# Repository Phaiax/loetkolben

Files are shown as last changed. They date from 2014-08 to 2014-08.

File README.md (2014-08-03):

##### Why?

The soldering iron station I used was much older than me and had a few drawbacks, including a random heat-to-infinity function if you don't pay attention. So I decided to renew it, but using the old housing and transformers.

##### PCB:

For more Information refer to the pcb, its full of comments.

+ pcb/alte_schaltung_*.*     - the legacy reverse engeneered pcb. (Including switch, trimmer and plugs which are not directly on the pcb)
+ pcb/neue_schaltung.*	     - my new pcb, double sided, excluding switches, the trimmer, the plugs.
+ pcb/out/		     - this is outdated and need to be regenerated! (the 7905 has different pinouts)

##### Features:

+ galvanic seperated
+ Auto timeout (currently 2 min)
+ Enough power (<30s to 300°C)
+ Temperature Display
+ Switch heat on @ zero passing of sine wave.
+ On and off via software (turn trim resistor to left/right dead stop)
+ Display in house temperature

##### Missing: 

+ a nice controller (kalman or at least something which can filter the white noise of the measurements). I really would like to improve this, but currently I'm using 2032 od 2048 bytes of flash. An AtTiny861A would have been better :(

##### Build:

+ If you should ever build this, make shure you understand every part of the hardware and the software. You need to calibrate the timer value and the temperature calculation coefficient and offset.
+ Depending on the used voltages and transformers, you may need to adjust some resistors etc.
+ Pay attention when handeling voltages above 30V, and even more attention with 110 or 230V. Always remove plug before opening the housing and vice versa.
+ I needed to force the position of the holes and the led to match the legacy pcb. You may want to move the holes.
+ Check which type of thermocouple (=thermoeelement) you are using and adjust the amplification if neccessary.

##### Possible improvements:

+ Use Attiny861A with 8000 instead of 2000 kb flash and add more features to the software.
+ Make the led to light up at both the positive and negative half wave.
+ Make some EMV improvements.
+ You probably can omit the negative voltage generation, the currently used opamp is capable of only using a positive one. (I former planed to use another opamp).
+ The polygons that create the ground area can be adjusted, so the triac and the led have more spacing to the surrounding ground area.

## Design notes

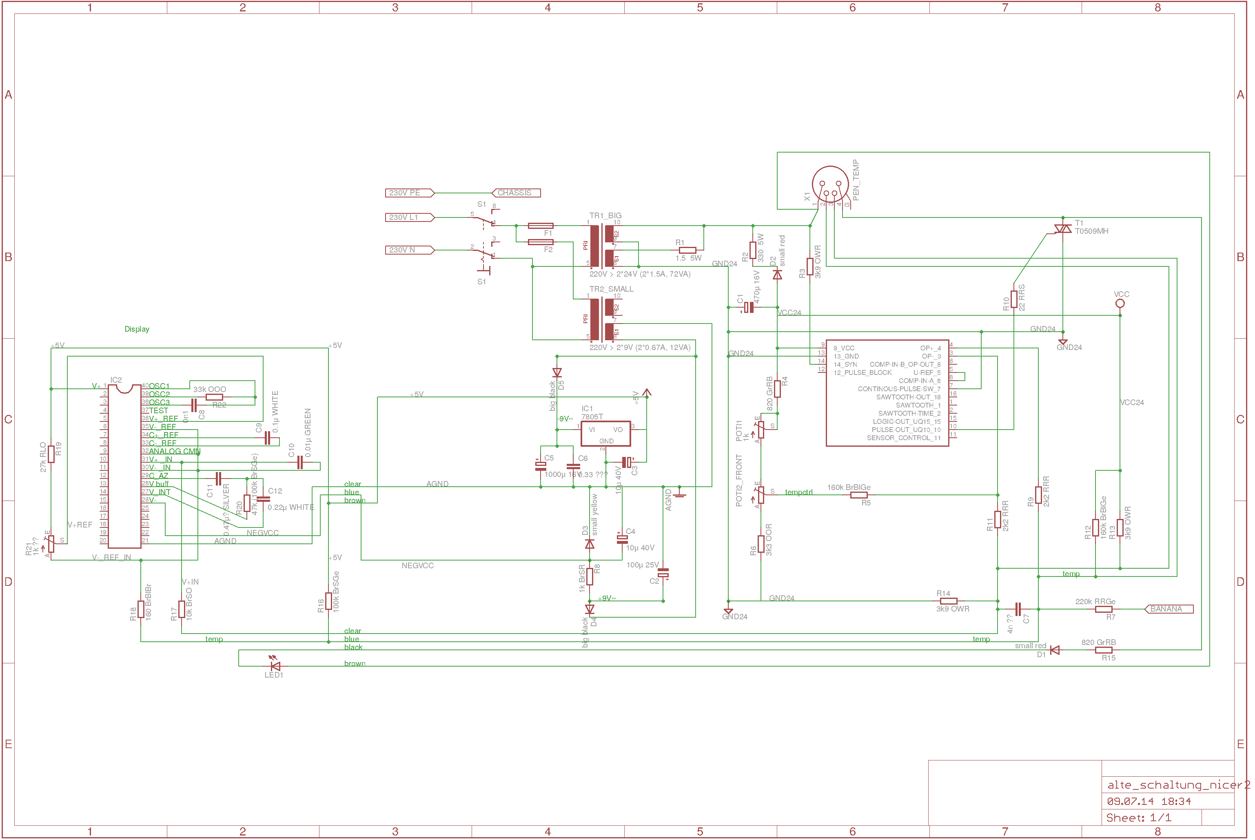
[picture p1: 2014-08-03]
pcb/schaltplan.png

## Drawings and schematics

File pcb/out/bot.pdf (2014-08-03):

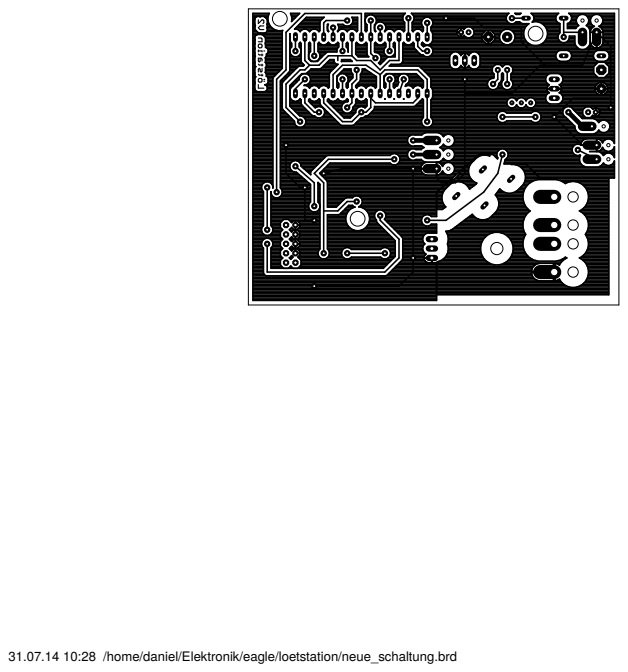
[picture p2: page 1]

31.07.14 10:28 /home/daniel/Elektronik/eagle/loetstation/neue_schaltung.brd

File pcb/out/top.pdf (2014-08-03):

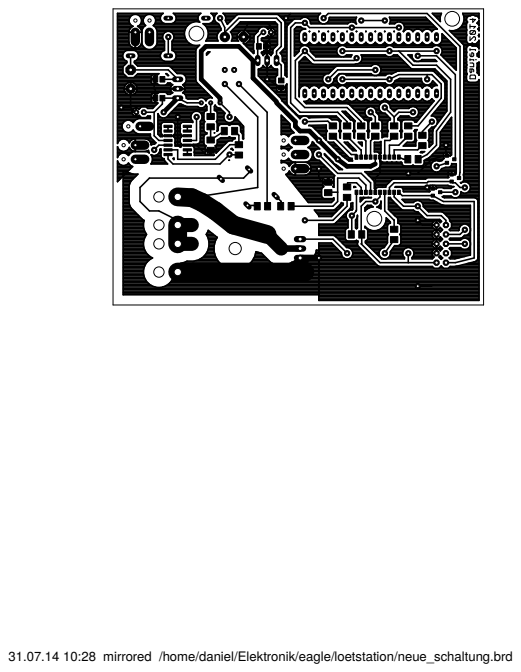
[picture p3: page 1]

31.07.14 10:28 mirrored /home/daniel/Elektronik/eagle/loetstation/neue_schaltung.brd

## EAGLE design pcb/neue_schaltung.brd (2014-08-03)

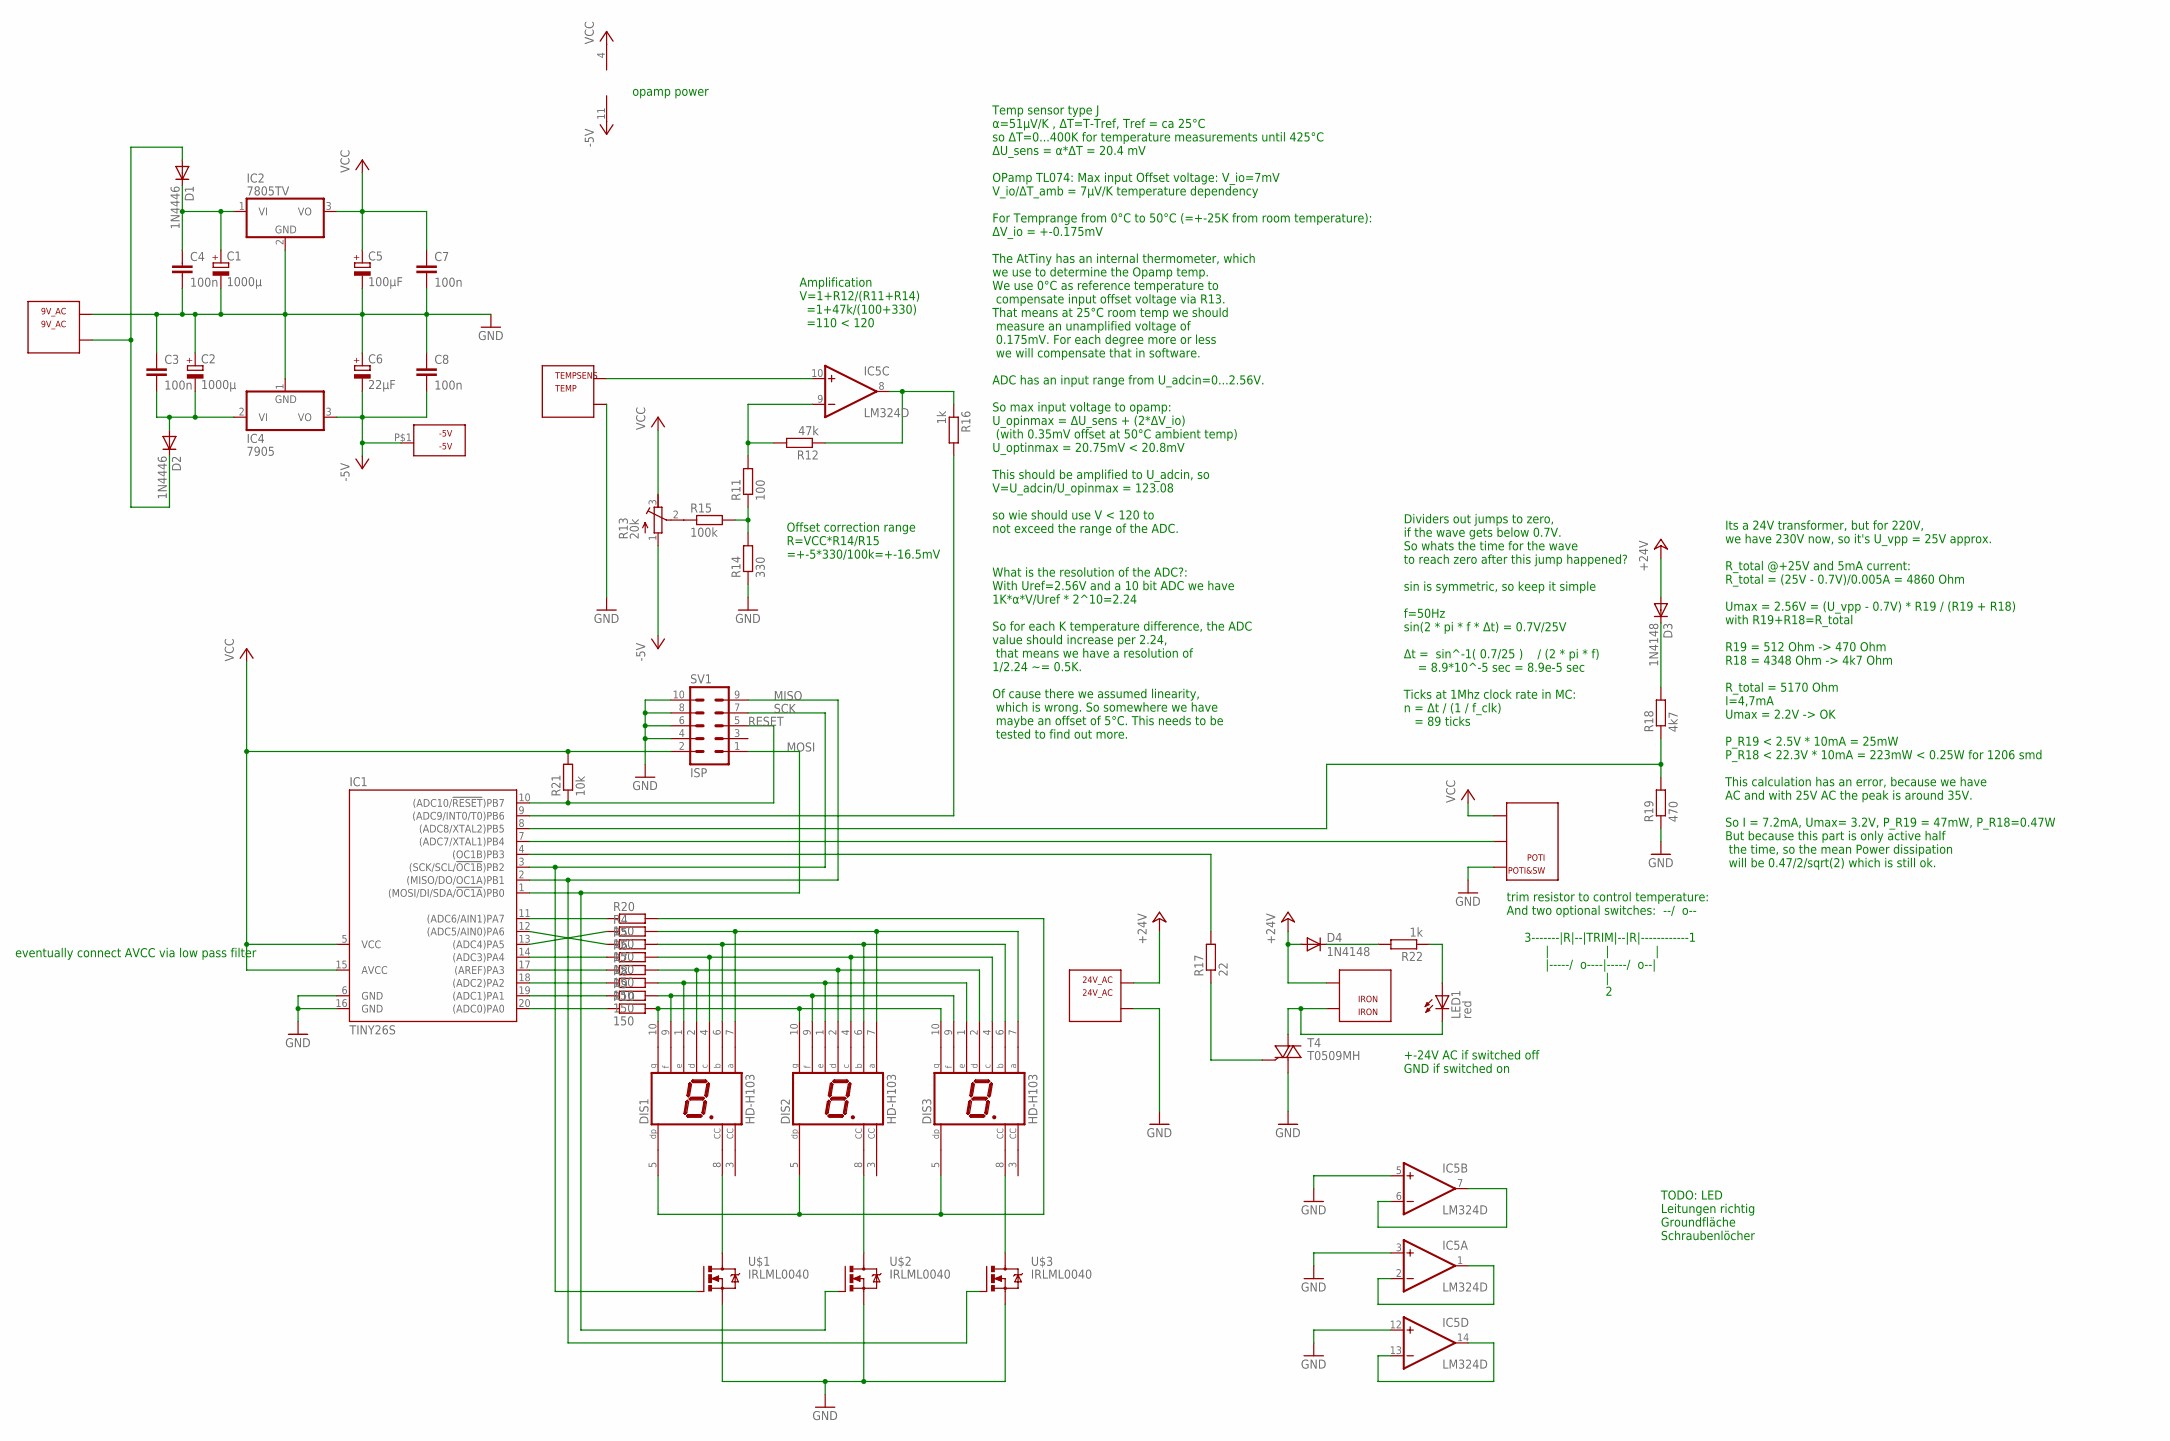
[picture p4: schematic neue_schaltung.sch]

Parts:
9V_AC: 9V_AC; WIREPADX2_2H
24V_AC: 24V_AC; WIREPADX2_2H_BIG
-5V: -5V; WIREPAD_2H
C1, C2: 1000µ; E5-10,5
C3, C4, C7, C8: 100n; C0805
C5: 100µF; E2-5
C6: 22µF; E2-5
D1, D2: 1N4446; DO35-10
D3, D4: 1N4148; DO35-10
DIS1, DIS2, DIS3: HD-H103; HDSP-M
IC1: TINY26S; SO20L
IC2: 7805TV; TO220V
IC4: 7905; TO220H
IC5: LM324D; SO14
IRON: IRON; WIREPADX2_2H_BIG
LED1: red; LED5MM
POTI&SW: POTI; WIREPADX3_2H
R4, R5, R6, R7, R8, R9, R10, R20: 150; M1206
R11: 100; M1206
R12: 47k; M1206
R13: 20k; RTRIM64W
R14: 330; M1206
R15: 100k; M1206
R16, R22: 1k; M1206
R17: 22; M1206
R18: 4k7; M1206
R19: 470; M1206
R21: 10k; M1206
SV1: ISP; ML10
T4: T0509MH; TO220AB
TEMPSENS: TEMP; WIREPADX2_2H
U$1, U$2, U$3: IRLML0040; MICRO3

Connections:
+24V: 24V_AC.P$1, D3.A, D4.A, IRON.P$2
-5V: -5V.P$1, C6.-, C8.2, IC4.3 (VO), IC5.11 (V-), R13.1 (E)
GND: 9V_AC.P$1, 24V_AC.P$2, C1.-, C2.+, C3.1, C4.2, C5.-, C6.+, C7.2, C8.1, IC1.6 (GND), IC1.16 (GND), IC2.2 (GND), IC4.1 (GND), IC5.3 (+IN), IC5.5 (+IN), IC5.12 (+IN), POTI&SW.P$1, R14.1, R19.1, SV1.4, SV1.6, SV1.8, SV1.10, T4.1 (A1), TEMPSENS.P$2, U$1.2 (S), U$2.2 (S), U$3.2 (S)
MISO: IC1.2 ((MISO/DO/OC1A)PB1), SV1.9, U$3.1 (G)
MOSI: IC1.1 ((MOSI/DI/SDA/!OC1A!)PB0), SV1.1, U$2.1 (G)
unnamed: DIS1.10 (G), DIS2.10 (G), DIS3.10 (G), R10.2
unnamed: DIS1.9 (F), DIS2.9 (F), DIS3.9 (F), R9.2
unnamed: DIS1.1 (E), DIS2.1 (E), DIS3.1 (E), R8.2
unnamed: DIS1.2 (D), DIS2.2 (D), DIS3.2 (D), R7.2
unnamed: DIS1.4 (C), DIS2.4 (C), DIS3.4 (C), R6.2
unnamed: DIS1.6 (B), DIS2.6 (B), DIS3.6 (B), R5.2
unnamed: DIS1.7 (A), DIS2.7 (A), DIS3.7 (A), R4.2
unnamed: DIS1.5 (DP), DIS2.5 (DP), DIS3.5 (DP), R20.2
unnamed: IC1.12 ((ADC5/AIN0)PA6), R5.1
unnamed: IC1.13 ((ADC4)PA5), R4.1
unnamed: IC1.14 ((ADC3)PA4), R6.1
unnamed: IC1.17 ((AREF)PA3), R7.1
unnamed: IC1.18 ((ADC2)PA2), R8.1
unnamed: IC1.19 ((ADC1)PA1), R9.1
unnamed: IC1.20 ((ADC0)PA0), R10.1
unnamed: DIS1.8 (CC), U$1.3 (D)
unnamed: DIS2.8 (CC), U$2.3 (D)
unnamed: DIS3.8 (CC), U$3.3 (D)
unnamed: IC5.10 (+IN), TEMPSENS.P$1
unnamed: R13.2 (S), R15.1
unnamed: 9V_AC.P$2, D1.A, D2.C
unnamed: C2.-, C3.2, D2.A, IC4.2 (VI)
unnamed: C1.+, C4.1, D1.C, IC2.1 (VI)
unnamed: IC5.9 (-IN), R11.2, R12.2
unnamed: IC1.9 ((ADC9/INT0/T0)PB6), R16.2
unnamed: R11.1, R14.2, R15.2
unnamed: IC5.8 (OUT), R12.1, R16.1
unnamed: IRON.P$1, LED1.K (C), T4.2 (A2)
unnamed: R17.1, T4.3 (G)
unnamed: IC1.4 ((OC1B)PB3), R17.2
unnamed: IC1.7 ((ADC7/XTAL1)PB4), POTI&SW.P$2
unnamed: IC1.8 ((ADC8/XTAL2)PB5), R18.1, R19.2
unnamed: D3.C, R18.2
unnamed: IC1.11 ((ADC6/AIN1)PA7), R20.1
unnamed: D4.C, R22.2
unnamed: IC5.6 (-IN), IC5.7 (OUT)
unnamed: IC5.1 (OUT), IC5.2 (-IN)
unnamed: IC5.13 (-IN), IC5.14 (OUT)
unnamed: LED1.A, R22.1
RESET: IC1.10 ((ADC10/!RESET!)PB7), R21.1, SV1.5
SCK: IC1.3 ((SCK/SCL/!OC1B!)PB2), SV1.7, U$1.1 (G)
VCC: C5.+, C7.1, IC1.5 (VCC), IC1.15 (AVCC), IC2.3 (VO), IC5.4 (V+), POTI&SW.P$3, R13.3 (A), R21.2, SV1.2

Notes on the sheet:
eventually connect AVCC via low pass filter
opamp power
Offset correction range R=VCC*R14/R15 =+-5*330/100k=+-16.5mV
Amplification V=1+R12/(R11+R14) =1+47k/(100+330) =110 < 120
Temp sensor type J α=51µV/K , ΔT=T-Tref, Tref = ca 25°C so ΔT=0...400K for temperature measurements until 425°C ΔU_sens = α*ΔT = 20.4 mV OPamp TL074: Max input Offset voltage: V_io=7mV V_io/ΔT_amb = 7µV/K temperature dependency For Temprange from 0°C to 50°C (=+-25K from room temperature): ΔV_io = 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
What is the resolution of the ADC?: With Uref=2.56V and a 10 bit ADC we have 1K*α*V/Uref * 2^10=2.24 So for each K temperature difference, the ADC value should increase per 2.24, that means we have a resolution of 1/2.24 ~= 0.5K. Of cause there we assumed linearity, which is wrong. So somewhere we 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
+-24V AC if switched off GND if switched on
trim resistor to control temperature: And two optional switches: --/ o-- 3-------|R|--|TRIM|--|R|------------1 | | | |-----/ o----|-----/ o--| | 2
Its a 24V transformer, but for 220V, we have 230V now, so it's U_vpp = 25V approx. R_total @+25V and 5mA current: R_total = (25V - 0.7V)/0.005A = 4860 Ohm Umax = 2.56V = (U_vpp - 0.7V) * R19 / (R19 + R18) with R19+R18=R_total R19 = 512 Ohm -> 470 Ohm R18 = 4348 Ohm -> 4k7 Ohm R_total = 5170 Ohm I=4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
Dividers out jumps to zero, if the wave gets below 0.7V. So whats the time for the wave to reach zero after this jump happened? sin is symmetric, so keep it simple f=50Hz sin(2 * pi * f * Δt) = 0.7V/25V Δt = sin^-1( 0.7/25 ) / (2 * pi * f) = 8.9*10^-5 sec = 8.9e-5 sec Ticks at 1Mhz clock rate in MC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
TODO: LED Leitungen richtig Groundfläche Schraubenlöcher

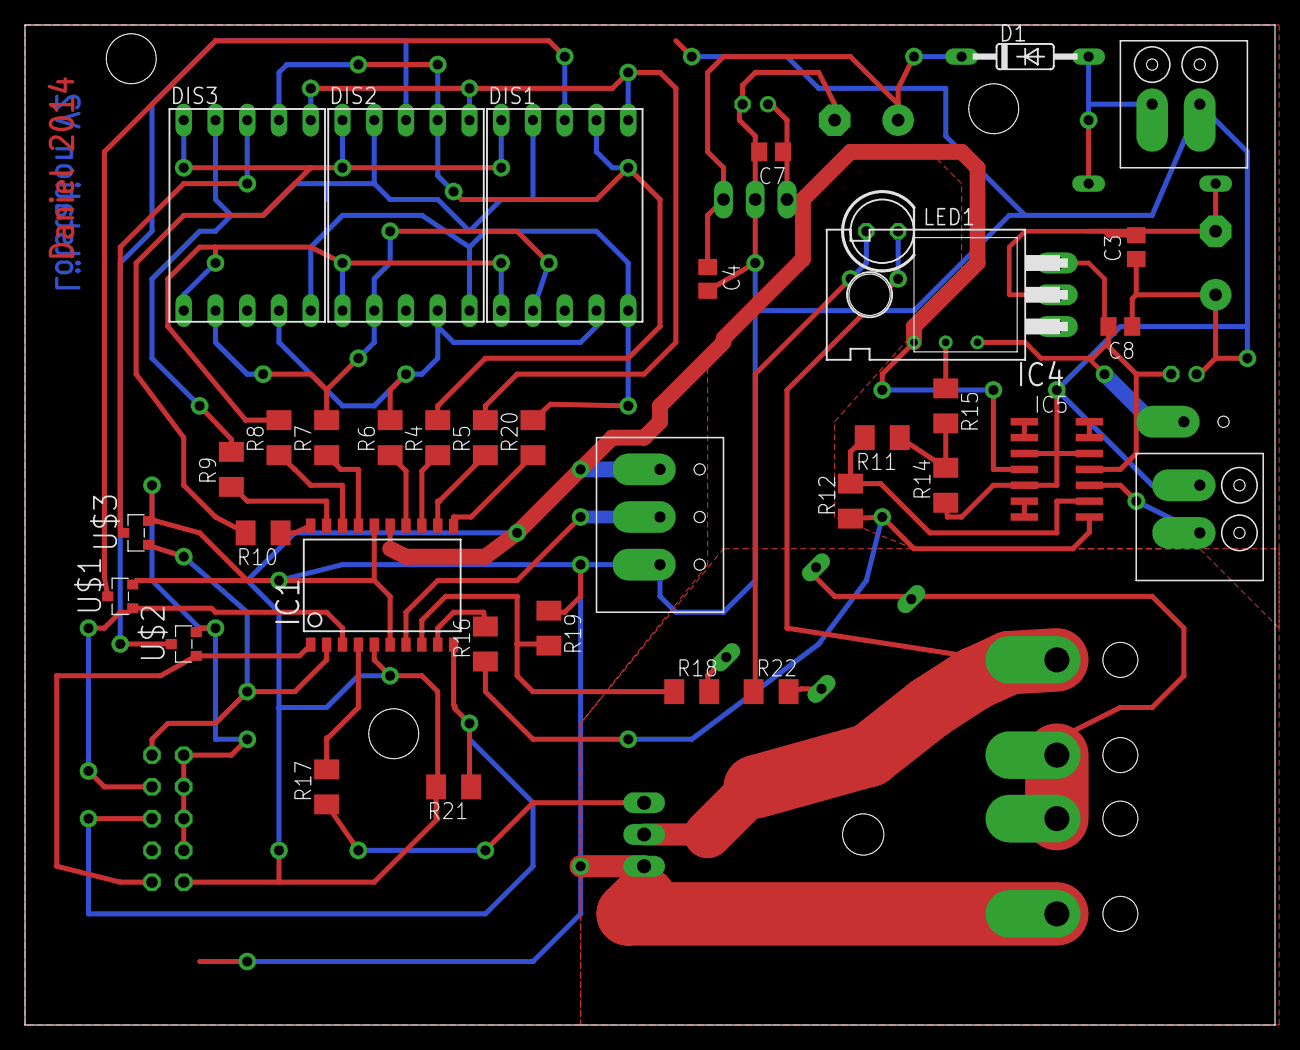
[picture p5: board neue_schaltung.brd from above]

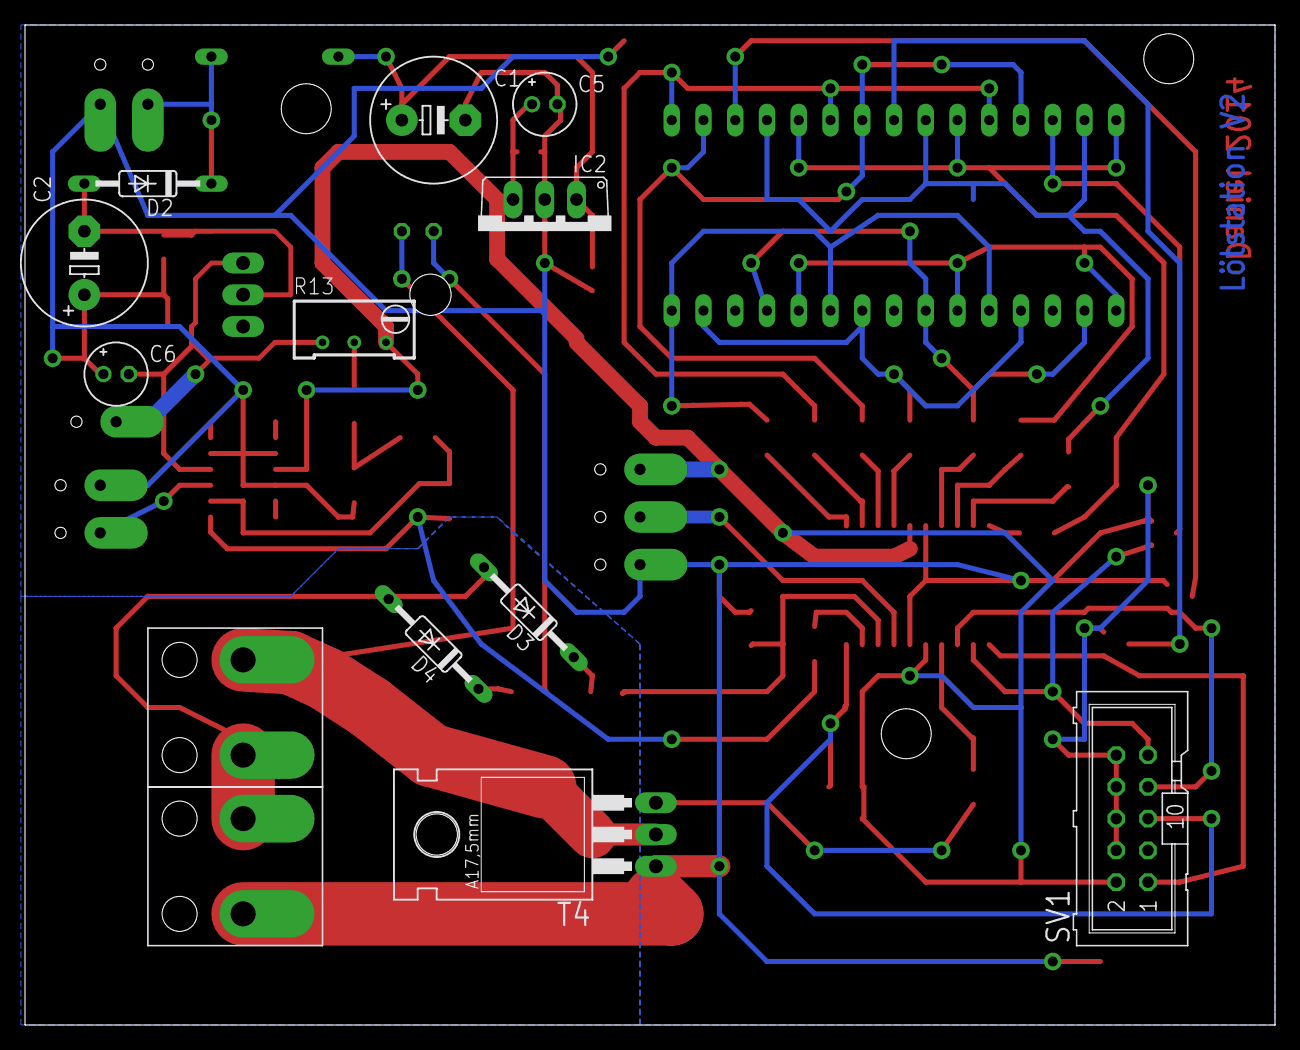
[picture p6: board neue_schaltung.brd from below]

Board: 2 copper layers, 100.0 x 80.0 mm, 50 parts (13 on the bottom side), 47 nets.

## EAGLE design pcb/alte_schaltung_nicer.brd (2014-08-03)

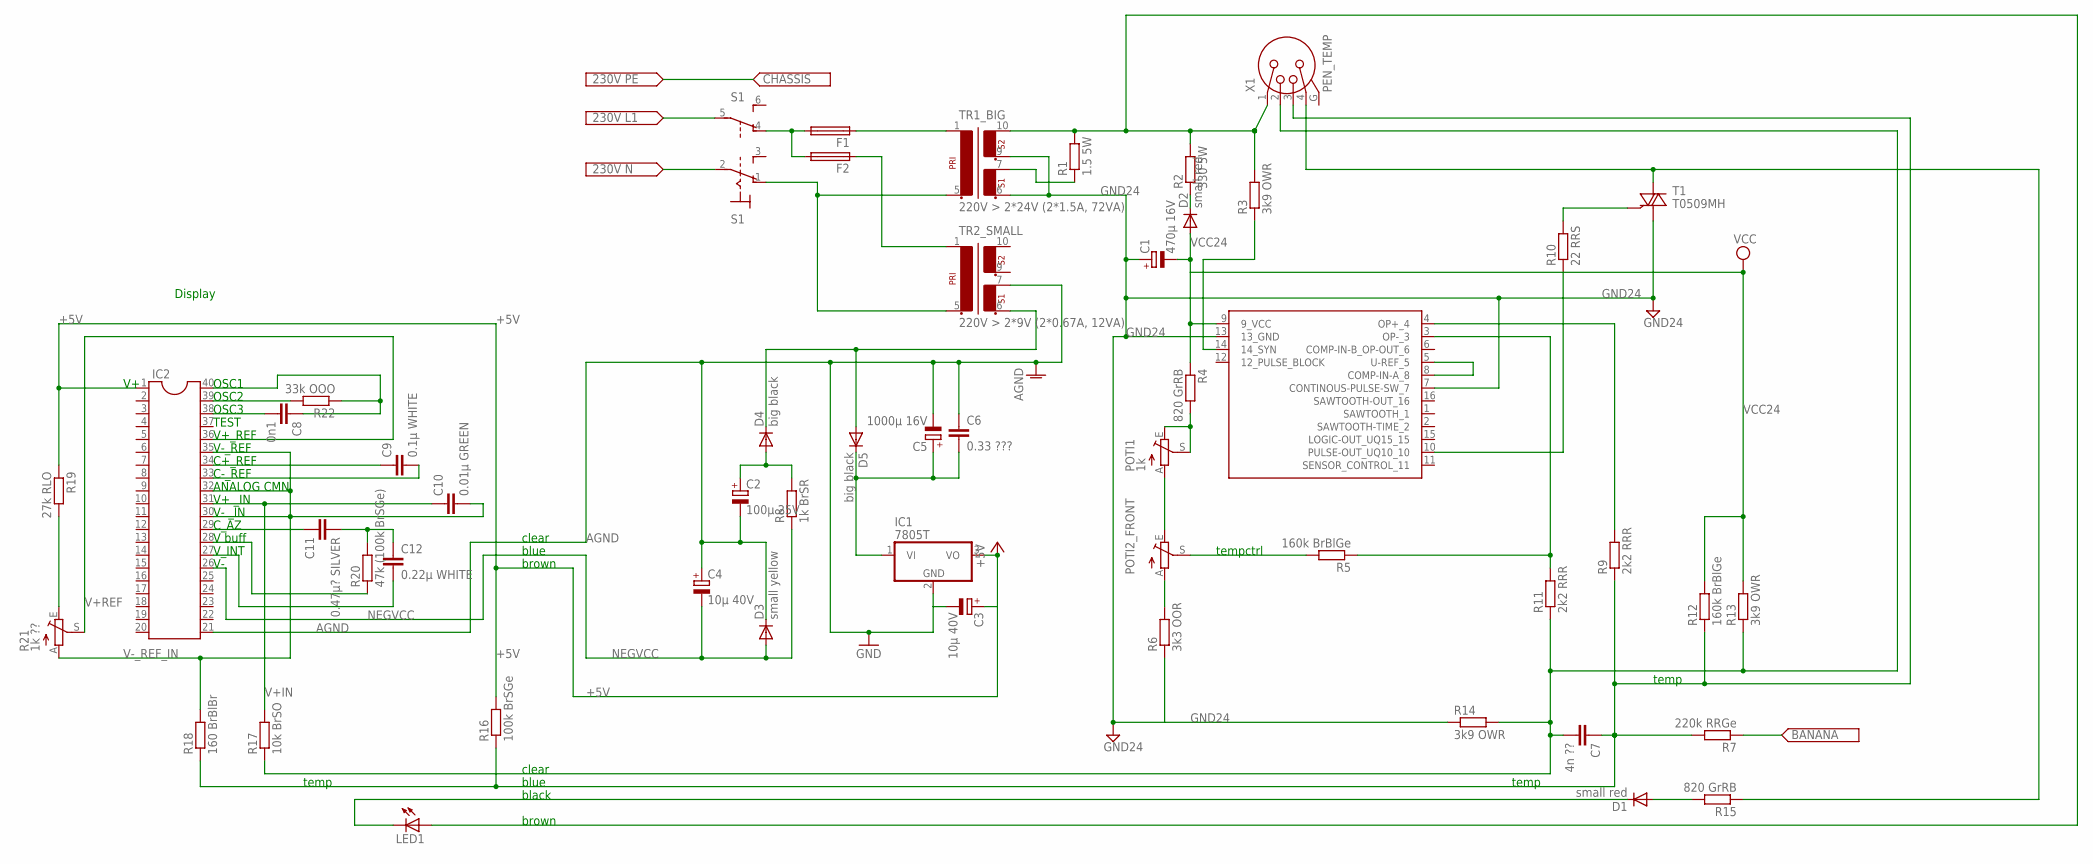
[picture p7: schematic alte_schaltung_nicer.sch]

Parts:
C1: 470µ 16V; E5-10,5
C2: 100µ 25V; E5-10,5
C3, C4: 10µ 40V; E5-10,5
C5: 1000µ 16V; E5-10,5
C6: 0.33 ???; C075-042X103
C7: 4n ??; C050-024X044
C8: 0n1; C050-024X044
C9: 0.1µ WHITE; C102-043X133
C10: 0.01µ GREEN; C102-043X133
C11: 0.47µ? SILVER; C102-043X133
C12: 0.22µ WHITE; C102-043X133
D1, D2: small red; DO41-10
D3: small yellow; DO35-10
D4, D5: big black; DO41-10
F1, F2: SH25
IC1: 7805T; TO220H
IC2: DIL40
LED1: LED3MM
POTI1: 1k; LI10
POTI2_FRONT: TRIM_EU-RJ9W; RJ9W
R1: 1.5 5W; 0922/22
R2: 330 5W; 0922/22
R3, R13, R14: 3k9 OWR; 0207/12
R4, R15: 820 GrRB; 0207/12
R5, R12: 160k BrBlGe; 0207/12
R6: 3k3 OOR; 0207/12
R7: 220k RRGe; 0207/12
R8: 1k BrSR; 0207/12
R9, R11: 2k2 RRR; 0207/12
R10: 22 RRS; 0207/12
R16: 100k BrSGe; 0207/12
R17: 10k BrSO; 0207/12
R18: 160 BrBlBr; 0207/12
R19: 27k RLO; 0207/12
R20: 47k (100k BrSGe); 0207/12
R21: 1k ??; SP19L
R22: 33k OOO; 0207/12
S1: 320-938
T1: T0509MH; TO220AB
TR1_BIG: 220V > 2*24V (2*1.5A, 72VA); EI42-2
TR2_SMALL: 220V > 2*9V (2*0.67A, 12VA); EI42-2
U$1: U106BS-DIL16; DIL16
X1: PEN_TEMP; NC4FBV

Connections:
+5V: C3.+, IC1.3 (VO), IC2.1, R16.2, R19.1
AGND: C2.-, C3.-, C4.+, C5.-, C6.1, D3.C, IC1.2 (GND), IC2.21, TR2_SMALL.7 (4)
GND24: C1.+, R6.1, R14.1, T1.1 (A1), TR1_BIG.6 (3), TR1_BIG.9 (5), U$1.7 (CONTINOUS-PULSE-SW_7), U$1.13 (13_GND)
unnamed: F1.2, F2.2, S1.4 (O)
unnamed: F1.1, TR1_BIG.1
unnamed: F2.1, TR2_SMALL.1
unnamed: S1.1 (O), TR1_BIG.5 (2), TR2_SMALL.5 (2)
unnamed: C12.2, IC2.27
unnamed: LED1.A, R1.2, R2.2, R3.2, TR1_BIG.10 (6), X1.1
unnamed: R1.1, TR1_BIG.7 (4)
unnamed: D4.C, D5.A, TR2_SMALL.6 (3)
unnamed: C2.+, D4.A, R8.2
unnamed: C5.+, C6.2, D5.C, IC1.1 (VI)
unnamed: D1.A, R15.2
unnamed: R9.2, U$1.4 (OP+_4)
unnamed: C7.1, R7.2, R9.1, R12.1, R16.1, R18.1, X1.3
unnamed: D1.C, LED1.K (C)
unnamed: POTI2_FRONT.S, R5.2
unnamed: C7.2, R11.1, R13.1, R14.2, R17.1, X1.2
unnamed: POTI2_FRONT.A, R6.2
unnamed: R15.1, T1.2 (A2), X1.4
unnamed: R5.1, R11.2, U$1.3 (OP-_3)
unnamed: D2.C, R2.1
unnamed: R19.2, R21.E
unnamed: POTI1.A, POTI2_FRONT.E
unnamed: POTI1.E, POTI1.S, R4.2
unnamed: R10.2, T1.3 (G)
unnamed: R10.1, U$1.10 (PULSE-OUT_UQ10_10)
unnamed: U$1.5 (U-REF_5), U$1.8 (COMP-IN-A_8)
unnamed: R3.1, U$1.14 (14_SYN)
unnamed: C8.2, IC2.38
unnamed: IC2.39, R22.2
unnamed: C8.1, IC2.40, R22.1
unnamed: IC2.28, R20.1
unnamed: C9.1, IC2.34
unnamed: C9.2, IC2.33
unnamed: C11.1, IC2.29
unnamed: C11.2, C12.1, R20.2
NEGVCC: C4.-, D3.A, IC2.26, R8.1
V+IN: C10.1, IC2.31, R17.2
V+REF: IC2.36, R21.S
V-_REF_IN: C10.2, IC2.30, IC2.32, IC2.35, R18.2, R21.A
VCC24: C1.-, D2.A, R4.1, R12.2, R13.2, U$1.9 (9_VCC)

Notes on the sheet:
Display
brown
black
blue
clear
temp
tempctrl
V buff
C_AZ
V_INT
ANALOG CMN
V- _IN
V+ _IN
C+_REF
C-_REF
V+_REF
V-_REF
OSC1
OSC2
OSC3
TEST

Board: 2 copper layers, 52 parts (0 on the bottom side), 43 nets, no tracks yet.

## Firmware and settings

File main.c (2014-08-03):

/*
 * main.c
 *
 *  Created on: 29.07.2014
 *      Author: daniel
 */

#include <avr/io.h>
#include <avr/power.h>
#include <avr/interrupt.h>
#include <stdint.h>

#include "bitmacros.h"

#include "display.h"
#include "temperature.h"
#include "adc.h"
#include "trim.h"
#include "defines.h"
#include "controller.h"


uint16_t counter = 0;
uint16_t timeout_counter = 0;

int main(void) {
	display_init();
	control_init();


	sei(); // enable global interrupts


	//start_temperature_read();
	start_trim_read();
	what_to_display = DISPLAY_TEMP;

	while(1) {

		counter++;


		if(counter % COUNTER_UPDATE_MODULO == 0) {

			trim_update();
			temperature_update();
			control_update();
			display_update();

			timeout_counter++;
			if(timeout_counter == TIMEOUT_TIME) {
				dot2 = 0;
			}

		}
	}
}

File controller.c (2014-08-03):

/*
 * controller.c
 *
 *  Created on: 02.08.2014
 *      Author: daniel
 */

#include "controller.h"
#include "display.h"
#include "bitmacros.h"
#include "defines.h"
#include "temperature.h"
#include "trim.h"
#include <stdint.h>
#include <avr/io.h>
#include <avr/interrupt.h>



// keep these values low, so there will be no overflow on
// heat_on_cycles_counter  < heat_on_cycles
int8_t heat_max_cycles = 0;
int8_t heat_on_cycles = 0;
int8_t heat_on_cycles_counter = 0;

// wait for interrupt on falling edge
// then wait via timer until wave gets zero
//   turn on trigger pin and stop timer
// heat will stay on the negative half wave
// heat will stay on on positive wave because trigger is still on
// wait for interrupt on rising edge
//   increment cycle counter -> same value now, on falling edge and on timer
//   now a) turn trigger off if heat_on_cycles_counter tells so
//       b) let trigger stay on if heat should continue
// interrupt on falling edge will occour
//   we still can set timer in case b),
//   but the timer will have no effect since trigger is still on


// PIN CHANGE interrupt
ISR(PCINT_vect) {
	if(dot2) { // general enable

		if((PINB & _BV(PINB5))) {  // RISING EDGE

			heat_on_cycles_counter ++;
			if(heat_on_cycles_counter > heat_max_cycles) {
				heat_on_cycles_counter = 0;
			}

			int8_t diff = heat_on_cycles_counter - heat_on_cycles;
			if(diff >= 0) { // off when heat_on_cycles_counter reached (==) heat_on_cycles
				cbi(PORTB, PB3); // switch heat off
			}
			// else: continue with heat on next neg and pos wave


		} else {	// FALLING EDGE


			sbi(TCCR0B, CS00);	// turn TIMER 0 on with no prescaler
		}
	} else {
		cbi(PORTB, PB3);
	}
}

ISR(TIMER0_COMPA_vect) { //TIMER0_OVF // TIMER0_COMPA // TIMER0_COMPB // TIMER0_CAPT
	// stop timer0
	TCCR0B = _BV(PSR0); // clear prescaler (we don't use it, so no problem at all)
						// sets CS00=0 -> also stops counting

	int8_t diff = heat_on_cycles_counter - heat_on_cycles;
	if(diff < 0) {
		sbi(PORTB, PB3); // switch heat on
	}

	// clear timer value
	TCNT0H = 0;
	TCNT0L = 0;
}


void control_init() {
	// TRIAC PIN
	sbi(DDRB, DDB3); // configure as out
	cbi(PORTB, PB3); // switch heat off

	// INTERRUPT for 24V sine wave sync pin
	// Init Pin8 PB5 PCINT13 for interrupt on toggle
	PCMSK0 = 0;
	PCMSK1 = _BV(PCINT13);
	sbi(GIMSK, PCIE1);

	// use timer0 for wait after pin toggle (sin wave sync)
	// INIT TIMER 0
	TCCR0A = _BV(TCW0); // 16 Bit mode
	//TCCR0B = 0;
	// Interrupt time: one LSB = 1e-6 sec, 1 wave @50Hz = 20000
	// one quater: 5000 = 0x1388;
	// from rising edge (2,2V) to point zero (0V): 1D10
	// from falling edge (???V) to point zero (0V): 0850 (timer triggers 99% before 0 is reached)
	OCR0B = 0x08;
	OCR0A = 0x50;

	sbi(TIMSK, OCIE0A); // interrupt if ocr0a is reached
	// to turn on with no prescaler: sbi(TCCR0B, CS00);

}


void control_update() {
	int16_t diff = (int16_t)trim_for_display - (int16_t)temp_for_display;
	if(diff > 20) {
		heat_max_cycles = 5;
		heat_on_cycles = 5;
		heat_on_cycles_counter = 0; // reset
		dot3 = 1;
	} else if(diff > 10) {
		heat_max_cycles = 5;
		heat_on_cycles = 2;
		heat_on_cycles_counter = 0; // reset
		dot3 = 1;
	} else if(diff > 5) {
		heat_max_cycles = 5;
		heat_on_cycles = 1;
		heat_on_cycles_counter = 0; // reset
		dot3 = 1;
	} else if(diff > 0) {
		heat_max_cycles = 20;
		heat_on_cycles = 3;
		heat_on_cycles_counter = 0; // reset
		dot3 = 1;
	} else {
		dot3 = 0;
		heat_max_cycles = 2;
		heat_on_cycles = 0; // off
	}
}

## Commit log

2014-07-29 solderingiron project init commit: display number on breadboard 7seg
2014-07-29 ADC read and display
2014-08-01 timer1 for display multiplex, trim range
2014-08-03 adding pcb
    [alte_schaltung.brd, alte_schaltung.sch, alte_schaltung_nicer.brd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]
